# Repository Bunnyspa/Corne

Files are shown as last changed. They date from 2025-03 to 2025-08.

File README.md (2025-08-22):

# Corne

[Corne](https://github.com/foostan/crkbd) V3 keyboard with various features to achieve:
- Low PCB print cost (i.e. reversibility)
- Easy hand soldering
- Symmetry

## Warning
I have **NOT** tested the PH 2.0mm battery connector yet. Let me know if it works.

## Features
- MX, Choc V1, and Choc V2 switch support
- Wired and wireless support
- Reversible PCB
- Through-hole and SMD diode support
- Default pinouts (i.e. you can use the default QMK or ZMK firmware)

### Wired
- OLED display support
- 6-pin USB-C as keyboard link

### Wireless
- nice!view support
- PH 2.0mm (and just plain through-hole pads) for battery
- Power switch at the north side, either front or back (your choice)

## Design Choice Explanation

### Keyboard link
- The 6-pin version is used for easier hand soldering
- TRRS is not used due to the lack of symmetry

### OLED pinout location is slightly to the left
- To counter the OLEDs having the display area slightly to the right
- To overlap nice!view pinout location

## Jumper Soldering

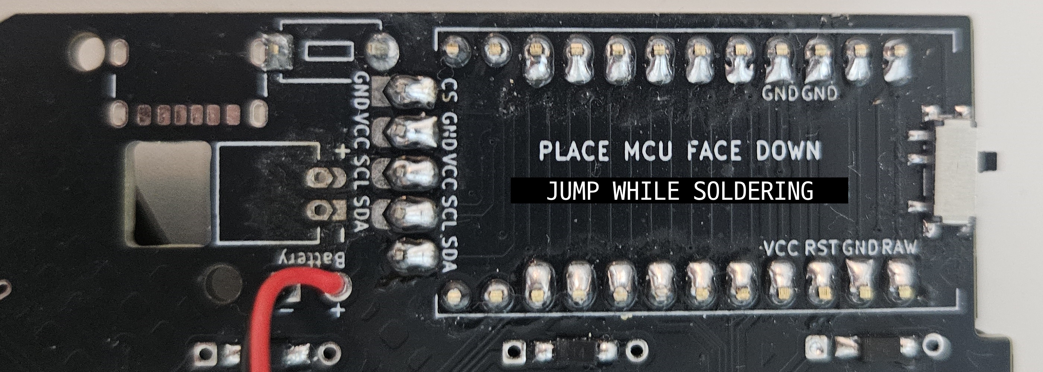
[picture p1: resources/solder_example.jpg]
Solder example

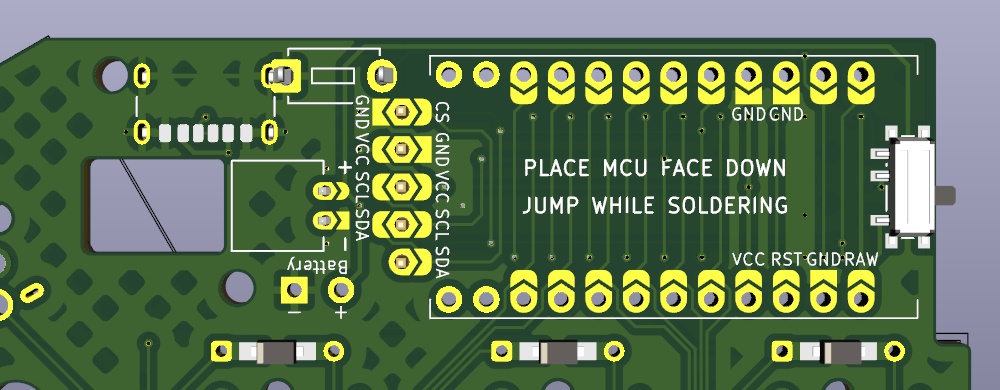
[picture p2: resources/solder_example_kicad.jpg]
Above image in KiCad

The images above show the backside.

To support the PCB reversibility, jumper pads are added (pretty much everywhere). The through-hole solder pads themselves are not connected to anything, so you need to connect jumpers together where you solder the pads.

### Display

For nice!view, you must connect the upper jumper pad (right side in the picture).

For 4-pin I2C OLEDs, you must connect the lower jumper pad (left side in the picture).

## IRL Testing
The PCB has been tested with these parts (per side):
- Solder PCB from JLCPCB
- nice!nano
- nice!view 3rd-party alternative (Taobao)
- 750mAh battery (to the plain through-hole pads)
- SPDT switch for power switch
- Tactile switch for reset switch
- Choc V2 switches
- 1N4148W SMD diodes
- Default ZMK Corne + nice!view firmware

I also tried Pro Micro + OLED combo with QMK, and they worked fine. (I did not fully build the Corne for this one. Just the MCU and the display.)

I have **NOT** tested the PH 2.0mm battery connector yet. Let me know if it works.

## Warning for Custom Firmware
The bottom 4 of MCU board pinouts do not support reversibility (hence no jumper pads). If your custom firmware uses these pins, you should configure pinouts for each side properly.

## PCB Preview
| Solder  | Hotswap |
| - | - |
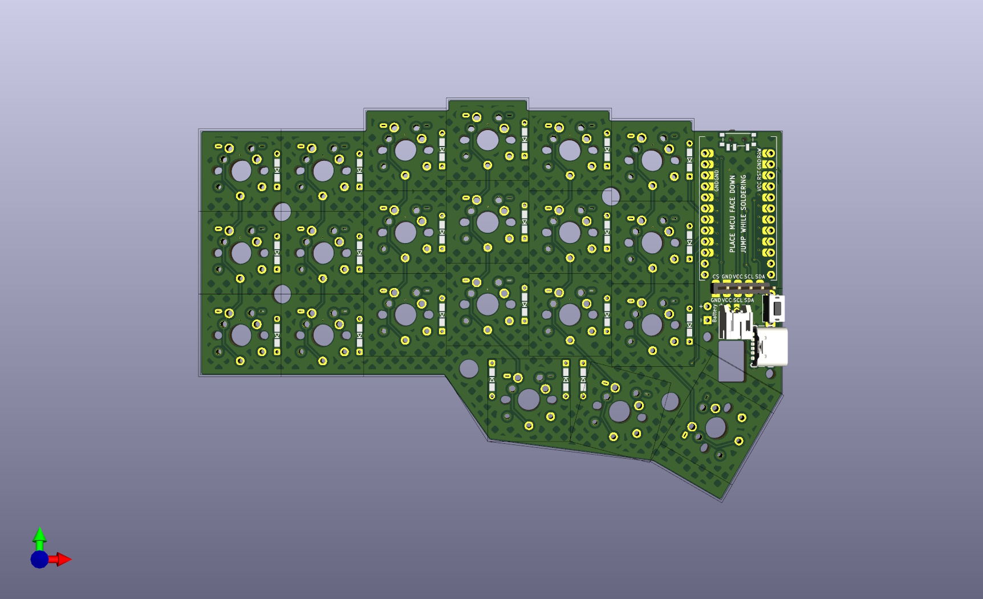
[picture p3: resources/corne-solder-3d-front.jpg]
Solder version front preview
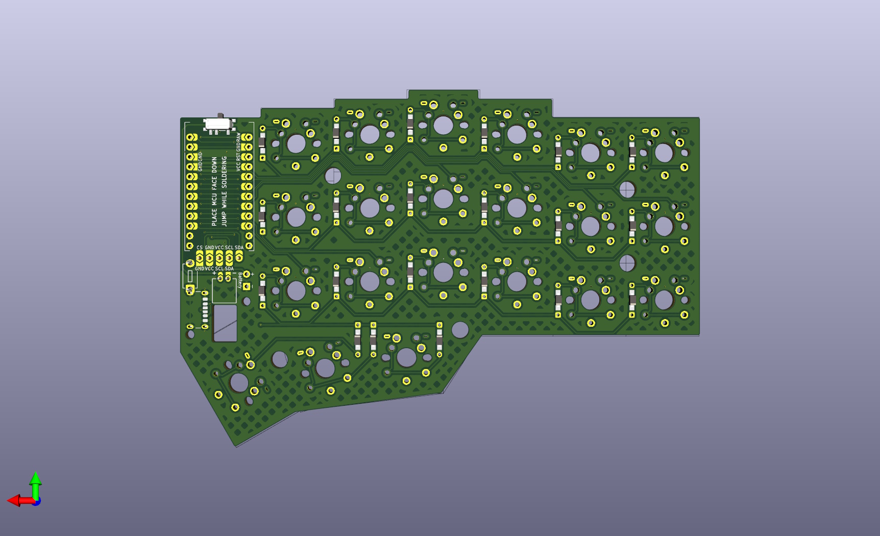
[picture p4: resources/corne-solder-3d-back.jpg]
Solder version back preview
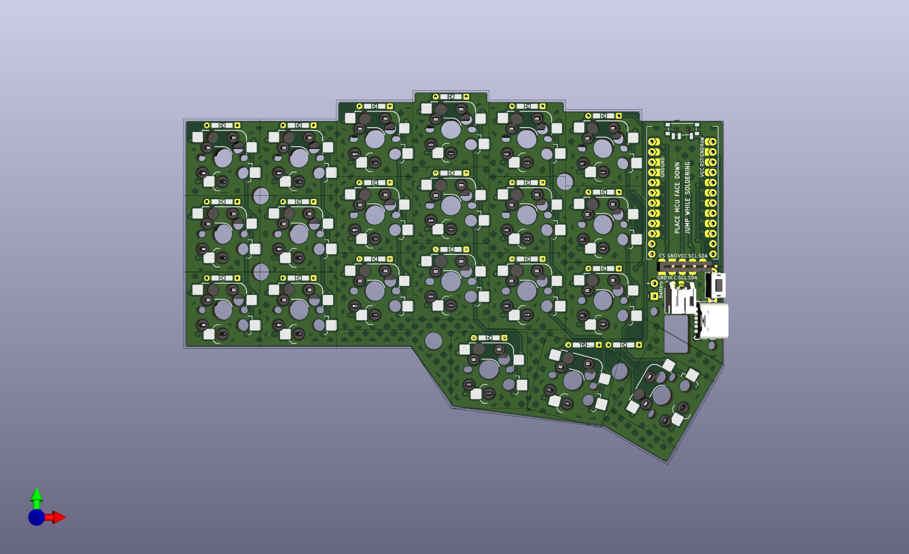
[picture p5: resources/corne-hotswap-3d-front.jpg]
Hotswap version front preview
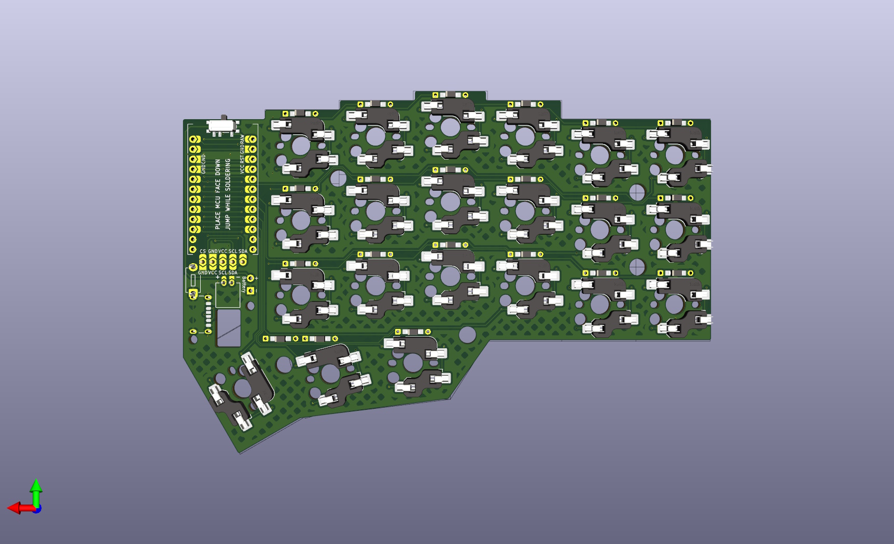
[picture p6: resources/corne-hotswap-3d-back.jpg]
Hotswap version back preview
|   |   |

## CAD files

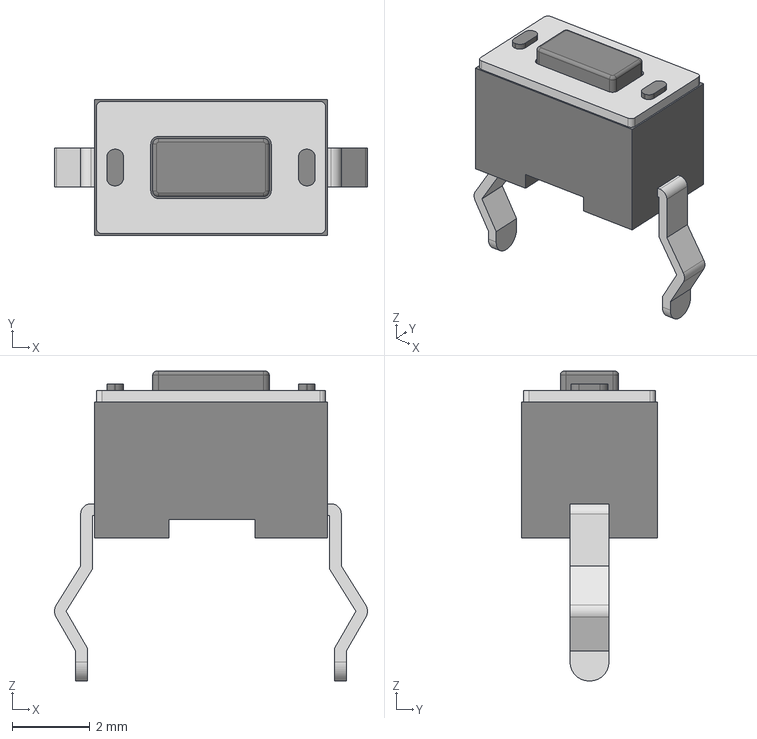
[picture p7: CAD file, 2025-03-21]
kicad-library/MJTP1243.stp
8.05 x 3.50 x 7.97 mm

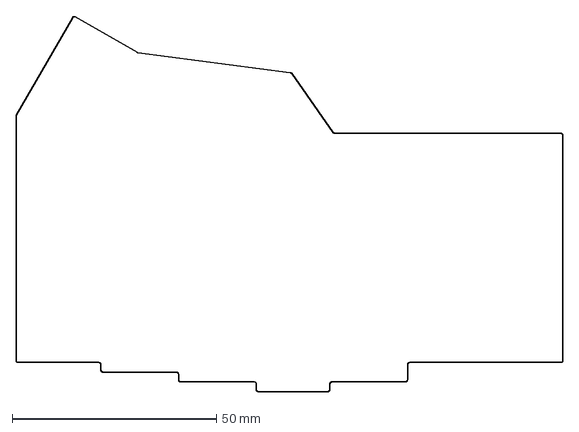
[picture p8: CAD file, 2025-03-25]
resources/edge.dxf
133.8 x 91.7 mm

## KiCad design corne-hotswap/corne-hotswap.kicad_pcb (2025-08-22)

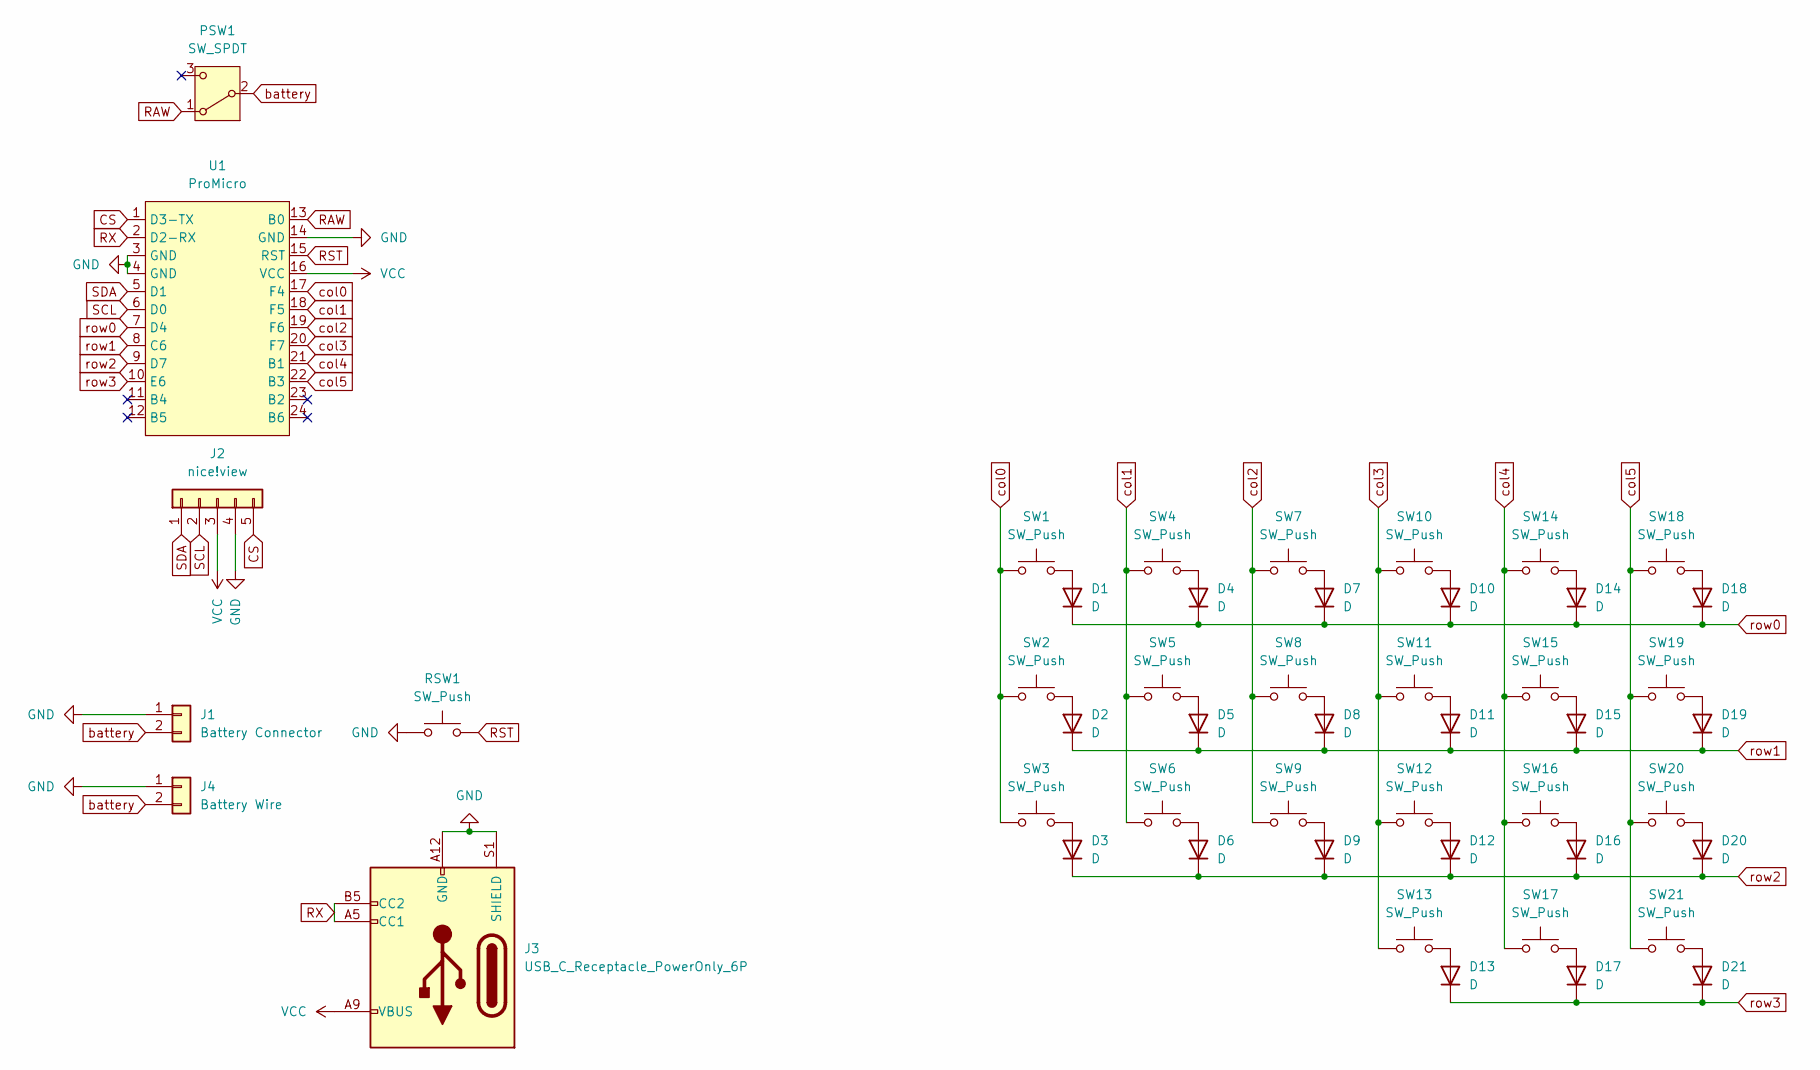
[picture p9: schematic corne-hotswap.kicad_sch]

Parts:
D1, D2, D3, D4, D5, D6, D7, D8, D9, D10, D11, D12, D13, D14, D15, D16, D17, D18, D19, D20, D21: D; Diode-Reversible
J1: Battery Connector; JST_PH_S2B-PH-K_1x02_P2.00mm_Horizontal
J2: nice!view; Nice_View
J3: USB_C_Receptacle_PowerOnly_6P; USB_C_Receptacle_GCT_USB4125-xx-x_6P_TopMnt_Horizontal
J4: Battery Wire
PSW1: SW_SPDT; SW_SPDT_PCM12
RSW1: SW_Push; SW_PUSH_1P1T_6x3.5mm_H4.3_APEM_MJTP1243
SW1, SW2, SW3, SW4, SW5, SW6, SW7, SW8, SW9, SW10, SW11, SW12, SW13, SW14, SW15, SW16, SW17, SW18, SW19, SW20, SW21: SW_Push; Switch-MX_ChocV2-Reversible-Hotswap
U1: ProMicro; Pro_Micro-Reversible

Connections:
CS: J2.5, U1.1 (D3-TX)
GND: J1.1, J2.4, J3.A12 (GND), J3.B12 (GND), J3.S1 (SHIELD), J4.1, RSW1.1, U1.3 (GND), U1.4 (GND), U1.14 (GND)
unnamed: D1.2 (A), SW1.2
unnamed: D2.2 (A), SW2.2
unnamed: D3.2 (A), SW3.2
unnamed: D4.2 (A), SW4.2
unnamed: D5.2 (A), SW5.2
unnamed: D6.2 (A), SW6.2
unnamed: D7.2 (A), SW7.2
unnamed: D8.2 (A), SW8.2
unnamed: D9.2 (A), SW9.2
unnamed: D10.2 (A), SW10.2
unnamed: D11.2 (A), SW11.2
unnamed: D12.2 (A), SW12.2
unnamed: D13.2 (A), SW13.2
unnamed: D14.2 (A), SW14.2
unnamed: D15.2 (A), SW15.2
unnamed: D16.2 (A), SW16.2
unnamed: D17.2 (A), SW17.2
unnamed: D18.2 (A), SW18.2
unnamed: D19.2 (A), SW19.2
unnamed: D20.2 (A), SW20.2
unnamed: D21.2 (A), SW21.2
RAW: PSW1.1 (A), U1.13 (B0)
RST: RSW1.2, U1.15 (RST)
RX: J3.A5 (CC1), J3.B5 (CC2), U1.2 (D2-RX)
SCL: J2.2, U1.6 (D0)
SDA: J2.1, U1.5 (D1)
VCC: J2.3, J3.A9 (VBUS), J3.B9 (VBUS), U1.16 (VCC)
battery: J1.2, J4.2, PSW1.2 (B)
col0: SW1.1, SW2.1, SW3.1, U1.17 (F4)
col1: SW4.1, SW5.1, SW6.1, U1.18 (F5)
col2: SW7.1, SW8.1, SW9.1, U1.19 (F6)
col3: SW10.1, SW11.1, SW12.1, SW13.1, U1.20 (F7)
col4: SW14.1, SW15.1, SW16.1, SW17.1, U1.21 (B1)
col5: SW18.1, SW19.1, SW20.1, SW21.1, U1.22 (B3)
row0: D1.1 (K), D4.1 (K), D7.1 (K), D10.1 (K), D14.1 (K), D18.1 (K), U1.7 (D4)
row1: D2.1 (K), D5.1 (K), D8.1 (K), D11.1 (K), D15.1 (K), D19.1 (K), U1.8 (C6)
row2: D3.1 (K), D6.1 (K), D9.1 (K), D12.1 (K), D16.1 (K), D20.1 (K), U1.9 (D7)
row3: D13.1 (K), D17.1 (K), D21.1 (K), U1.10 (E6)

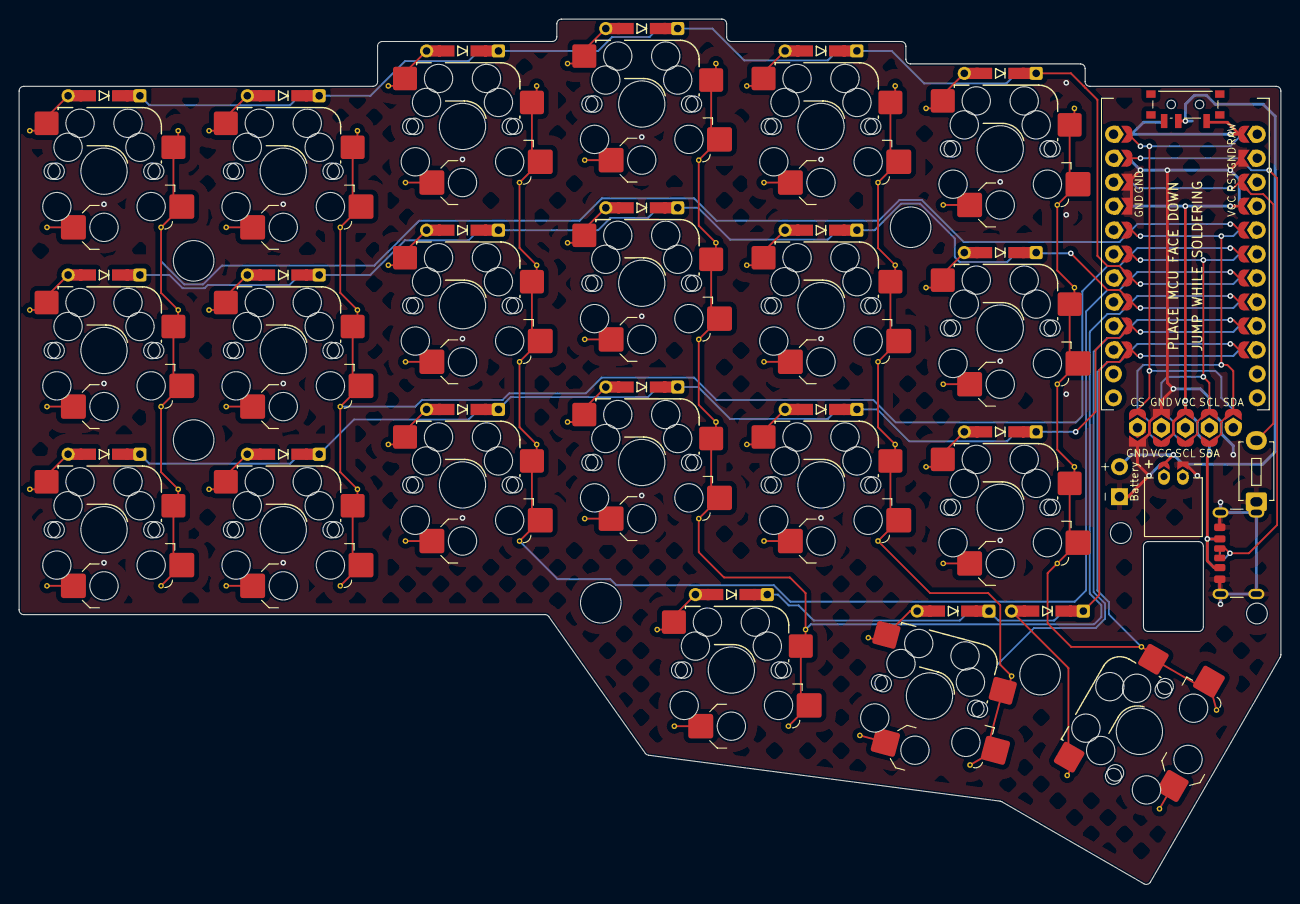
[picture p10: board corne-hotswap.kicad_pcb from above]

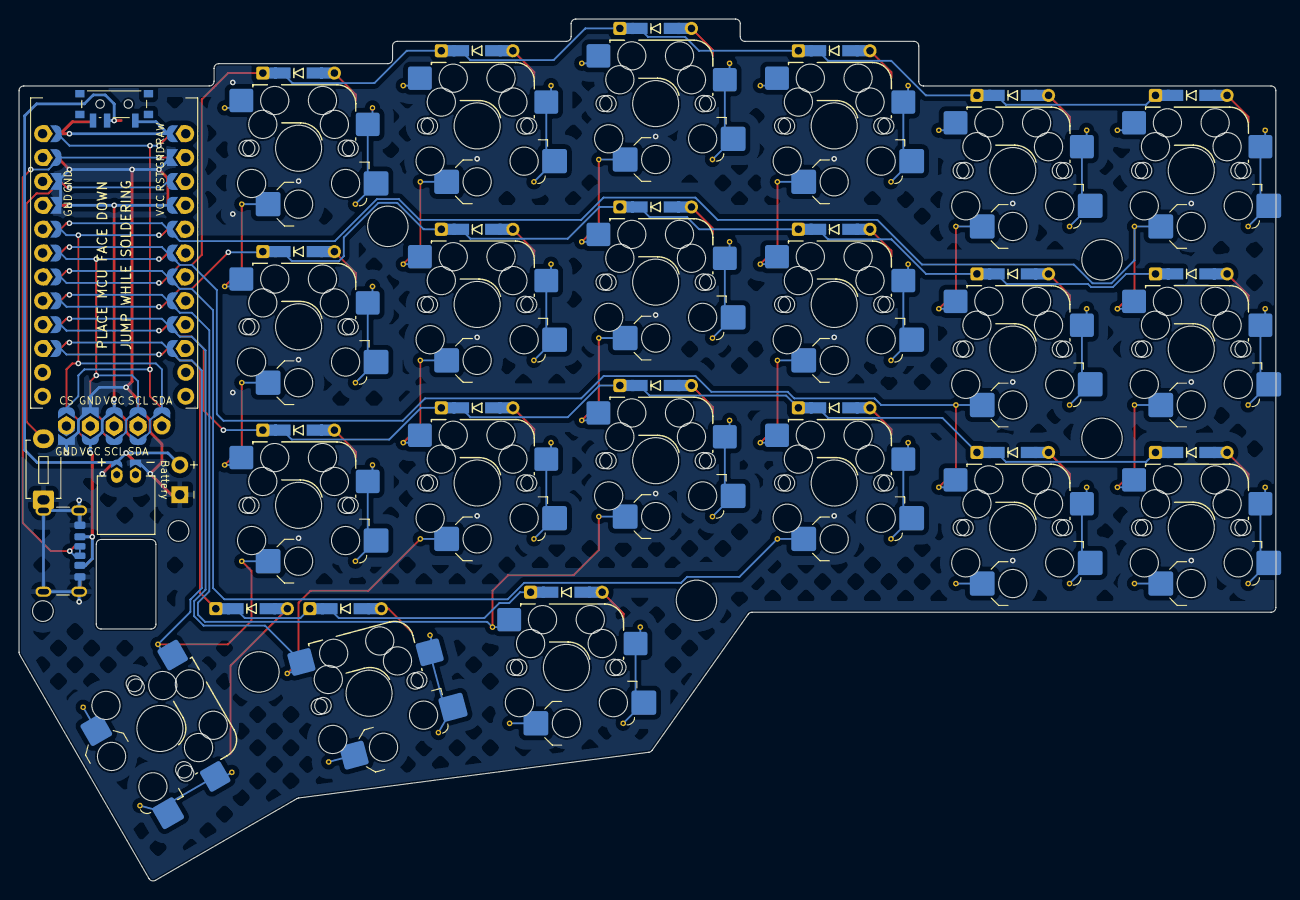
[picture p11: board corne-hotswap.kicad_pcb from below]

Board: 2 copper layers, 133.8 x 91.7 mm, 49 parts (22 on the bottom side), 40 nets.

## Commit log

2025-03-21 more footprints
2025-03-21 footprint assign
    [corne-hotswap.kicad_sch]
2025-03-21 remove wrong footprint from reset switch
    [corne-hotswap.kicad_sch]
2025-03-21 Update lib
    [MJTP1243.stp]
2025-03-21 pcb edit
    [corne-hotswap.kicad_pcb, corne-hotswap.kicad_sch]
2025-03-22 add solder version
    [corne-solder.kicad_pcb, corne-solder.kicad_sch]
2025-03-22 move future project to wip dir
    [corne-hotswap.kicad_pcb, corne-hotswap.kicad_sch]
2025-03-23 more wiring and DRC
    [corne-solder.kicad_pcb]
2025-03-23 move niceview jump pads
    [corne-solder.kicad_pcb]
2025-03-24 jump pads edit
    [corne-solder.kicad_pcb]
2025-03-24 More jump pads
    [corne-solder.kicad_pcb, corne-solder.kicad_sch]
2025-03-24 add bridge for wired
    [corne-solder.kicad_pcb, corne-solder.kicad_sch]
2025-03-25 edit pcb
    [corne-solder.kicad_pcb]
2025-03-25 Add measurements
    [corne-solder.kicad_pcb]
2025-03-25 add fillet to corners
    [corne-solder.kicad_pcb]
2025-03-25 add resource dir
    [edge.dxf]
2025-03-25 add edge cut guide line
    [corne-solder.kicad_pcb]
2025-03-26 silkscreen label and description change
    Labels now indicate jumper pads. Description is changed to clarify what labels are indicating.
    [corne-solder.kicad_pcb]
2025-03-26 add battery wire pads
    [corne-solder.kicad_pcb, corne-solder.kicad_sch]
2025-03-26 Add batt silks
    [corne-solder.kicad_pcb]
2025-03-26 update copper fill
    [corne-solder.kicad_pcb]
2025-03-26 change after running fab toolkit
    [corne-solder.kicad_pcb]
2025-03-26 small track change
    [corne-solder.kicad_pcb]
2025-03-26 add wip hotswap
    [corne-hotswap.kicad_pcb, corne-hotswap.kicad_sch]
2025-03-26 diode footprint edit
    [corne-hotswap.kicad_pcb, corne-solder.kicad_pcb]
2025-03-26 hotswap switch footprint change
    [corne-hotswap.kicad_pcb]
2025-03-26 Revert "hotswap switch footprint change"
    This reverts commit 98a31c7d3c40b55c292cbbfedf432d9a1d5aac7c.
    [corne-hotswap.kicad_pcb]
2025-03-26 column wiring
    [corne-hotswap.kicad_pcb]
2025-03-27 rename hotswap directory
    [corne-hotswap.kicad_pcb, corne-hotswap.kicad_sch]
2025-04-01 move cs to default pinout
    [corne-hotswap.kicad_sch, corne-solder.kicad_sch]
2025-04-01 major edit
    [corne-solder.kicad_pcb]
2025-04-02 new design (using module)
    [corne-hotswap.kicad_pcb, corne-solder.kicad_pcb]
2025-04-02 wiring update
    [corne-hotswap.kicad_pcb, corne-module.kicad_pcb, corne-solder.kicad_pcb]
2025-04-03 minor wiring update
    [corne-hotswap.kicad_pcb, corne-module.kicad_pcb, corne-solder.kicad_pcb]
2025-04-03 module wiring update
    [corne-hotswap.kicad_pcb, corne-module.kicad_pcb, corne-solder.kicad_pcb]
2025-04-04 pad shape change
    [corne-hotswap.kicad_pcb, corne-module.kicad_pcb, corne-solder.kicad_pcb]
2025-04-11 edit jumpers and texts
    [corne-hotswap.kicad_pcb, corne-module.kicad_pcb, corne-solder.kicad_pcb]
2025-04-24 edit display footprint
    [corne-hotswap.kicad_pcb, corne-module.kicad_pcb, corne-solder.kicad_pcb]
2025-08-15 instruction and battery jst hole update
    [corne-hotswap.kicad_pcb, corne-module.kicad_pcb, corne-solder.kicad_pcb]
2025-08-22 Edit to reflect current version label
